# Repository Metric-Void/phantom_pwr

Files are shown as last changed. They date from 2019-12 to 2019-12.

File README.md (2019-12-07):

# Phantom Power Supply
## Description
This is a standalone power supply for phantom power microphones. 48V Phantom power is "injected" into the wire to power the microphone, and the output can be directly sent to computers, phones, etc.

Power supply range is 12V-19V by design. Voltages close to this may work, but not guaranteed. The DC-DC converter circuit is designed to output 0.5A, well above the requirement for a single microphone. The circuit can be expanded to supply more microphones.

## Usage
This project is designed with Autodesk EAGLE PCB. Free versions would be enough since it have only one schematic and one board. Simply clone into your Documents/EAGLE/projects folder, and open the epf file.

The completed circuit board should be placed in a shielded, metal enclosure to prevent noise.

## Licence
NO WARRANTY OF ANY KIND. Free for educational and hobbyist use. Contact for commercial use.

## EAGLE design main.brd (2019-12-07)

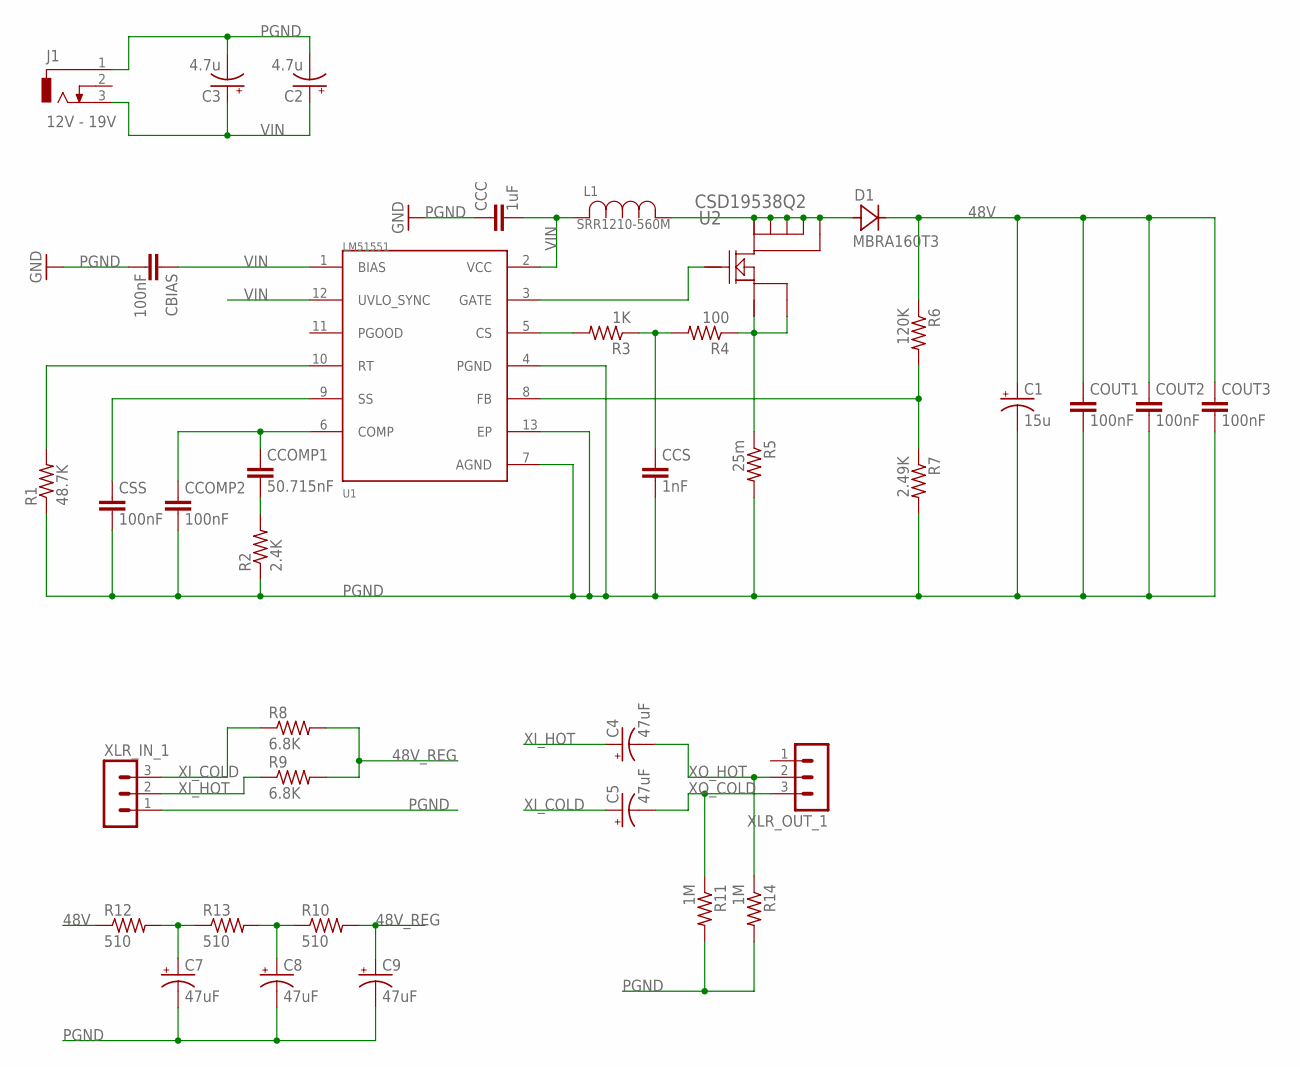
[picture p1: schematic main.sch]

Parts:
C1: 15u; CT7343
C2, C3: 4.7u; CT7343
C4, C5, C7, C8, C9: 47uF; 153CLV-0810
CBIAS: 100nF; C0805
CCC: 1uF; C0805
CCOMP1: 50.715nF; C0805
CCOMP2: 100nF; C0805
CCS: 1nF; C0805
COUT1, COUT2, COUT3: 100nF; C0805
CSS: 100nF; C0805
D1: MBRA160T3; SMA
J1: 12V - 19V; DCJ0303
L1: SRR1210-560M; IND_BOURNS_SRR1210
R1: 48.7K; R0805
R2: 2.4K; R0805
R3: 1K; R0805
R4: 100; R0805
R5: 25m; R1206
R6: 120K; R0805
R7: 2.49K; R0805
R8, R9: 6.8K; R1206
R10, R12, R13: 510; R1206
R11, R14: 1M; R0805
U1: LM51551; SON45P300X300X80-13N
U2: CSD19538Q2; DQK0006C
XLR_IN_1: MA03-1
XLR_OUT_1: MA03-1

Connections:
48V: C1.+, COUT1.1, COUT2.1, COUT3.1, D1.C, R6.1, R12.1
48V_REG: C9.+, R8.2, R9.2, R10.2
unnamed: R1.2, U1.10 (RT)
unnamed: CSS.1, U1.9 (SS)
unnamed: CCOMP1.2, R2.2
unnamed: CCOMP1.1, CCOMP2.1, U1.6 (COMP)
unnamed: R4.1, R5.1, U2.4 (SOURCE_2), U2.7 (SOURCE_1)
unnamed: R3.2, U1.5 (CS)
unnamed: CCS.1, R3.1, R4.2
unnamed: U1.3 (GATE), U2.3 (GATE)
unnamed: D1.A, L1.1, U2.1 (DRAIN_1), U2.2 (DRAIN_2), U2.5 (DRAIN_3), U2.6 (DRAIN_4), U2.8 (DRAIN_5)
unnamed: R6.2, R7.1, U1.8 (FB)
unnamed: C8.+, R10.1, R13.2
unnamed: C7.+, R12.2, R13.1
PGND: C1.-, C2.-, C3.-, C7.-, C8.-, C9.-, CBIAS.2, CCC.1, CCOMP2.2, CCS.2, COUT1.2, COUT2.2, COUT3.2, CSS.2, J1.1, R1.1, R2.1, R5.2, R7.2, R11.2, R14.2, U1.4 (PGND), U1.7 (AGND), U1.13 (EP), XLR_IN_1.1
VIN: C2.+, C3.+, CBIAS.1, CCC.2, J1.3, L1.2, U1.1 (BIAS), U1.2 (VCC), U1.12 (UVLO_SYNC)
XI_COLD: C5.+, R8.1, XLR_IN_1.3
XI_HOT: C4.+, R9.1, XLR_IN_1.2
XO_COLD: C5.-, R11.1, XLR_OUT_1.3
XO_HOT: C4.-, R14.1, XLR_OUT_1.2

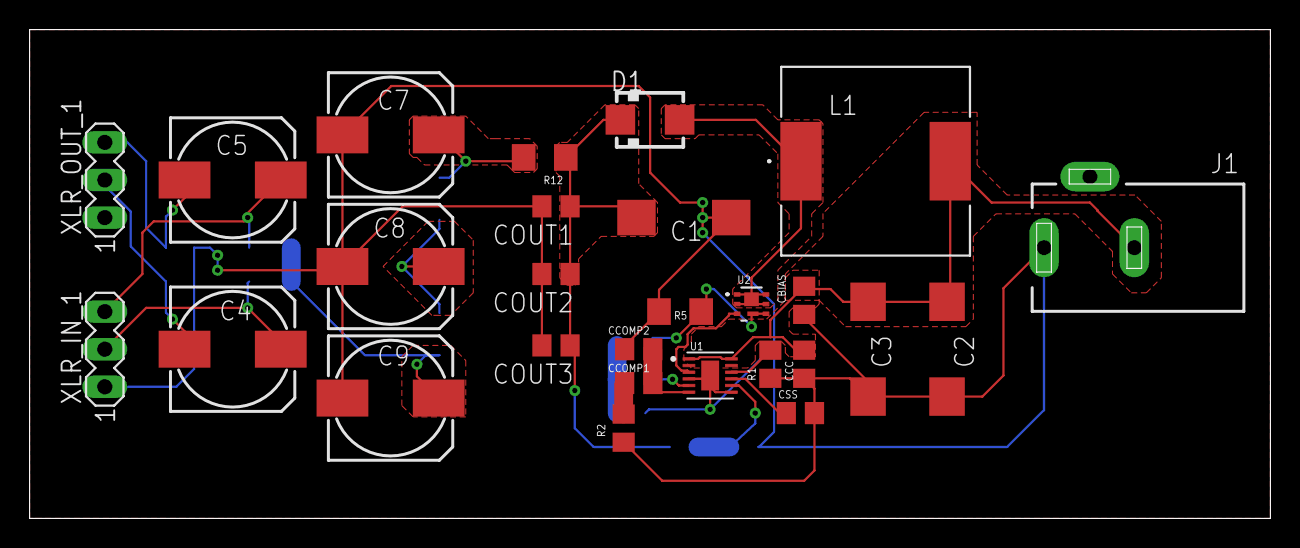
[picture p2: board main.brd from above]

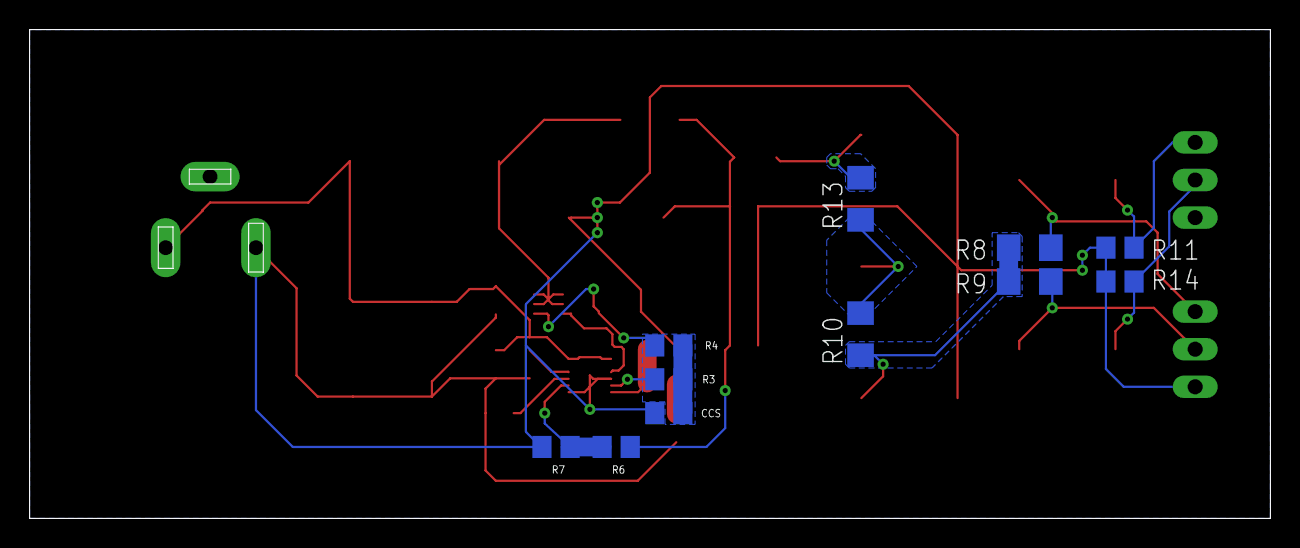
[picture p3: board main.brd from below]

Board: 2 copper layers, 83.8 x 33.0 mm, 38 parts (11 on the bottom side), 20 nets.
